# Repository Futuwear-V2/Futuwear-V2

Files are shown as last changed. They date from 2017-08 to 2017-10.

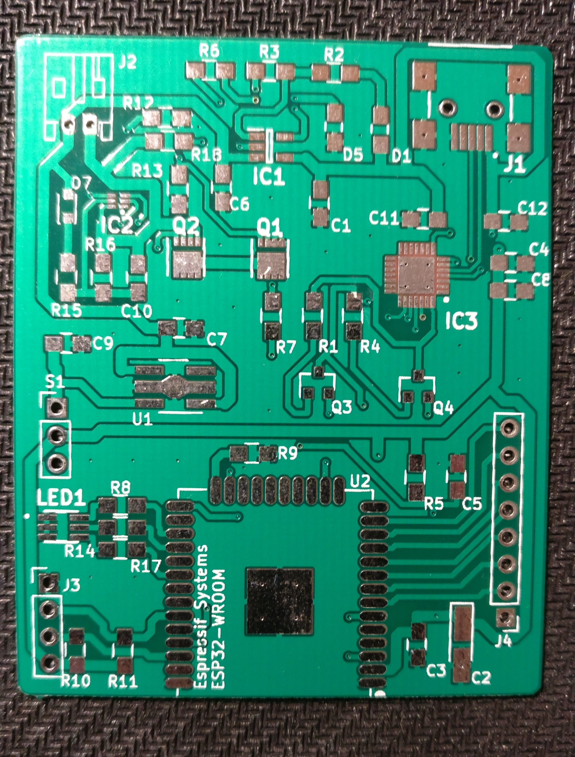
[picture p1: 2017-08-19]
Nettisivu/images/pcb_irl_no_components.jpg

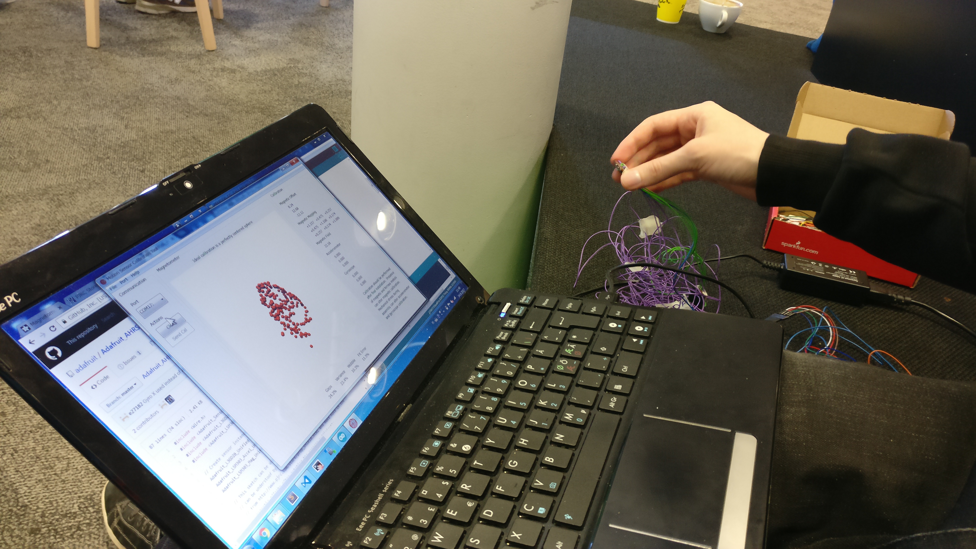
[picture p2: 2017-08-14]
Nettisivu/images/Magnetometer_test.jpg

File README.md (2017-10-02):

# Futuwear-V2
Protopaja 2017 group 11

Smart clothing motion capture shirt using ESP32 microcontroller and MPU-9250 IMUs.

To install the Arduino code on your ESP32, you need https://github.com/espressif/arduino-esp32 and the provided libraries. If you use the schematic, please note that the EN and IO0 pins need to be connected to ground when you upload the code to the device.

Guide on how to setup the server in /Server/README.md

Promotional website in /Nettisivu

Group members:
Jere Pylkkänen
Bruce Clayhills
Elliot Kölhi

https://protopaja.aalto.fi/futuricec/

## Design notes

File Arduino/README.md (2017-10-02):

# Futuwear-V2
How to setup the Arduino code on ESP32:
1. Install Arduino IDE and https://github.com/espressif/arduino-esp32
2. Copy the provided libraries to your Arduino libraries folder (usually Documents/Arduino/libraries on Windows)
3. Configure the WiFi settings and the IP address of the UDP server in FutuwearV2_UDP.ino
4. Upload FutuwearV2_UDP.ino to your ESP32

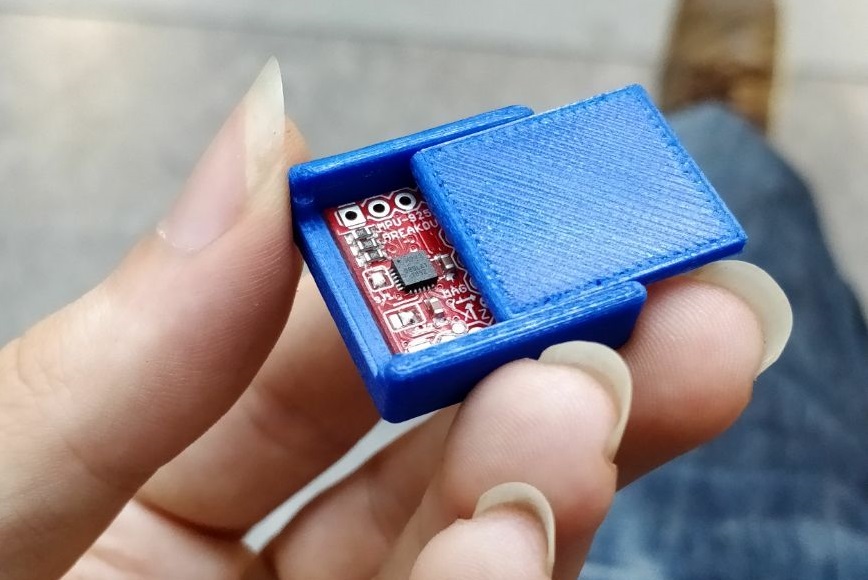
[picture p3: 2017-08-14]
Nettisivu/images/MPU-9250_IRL.jpg

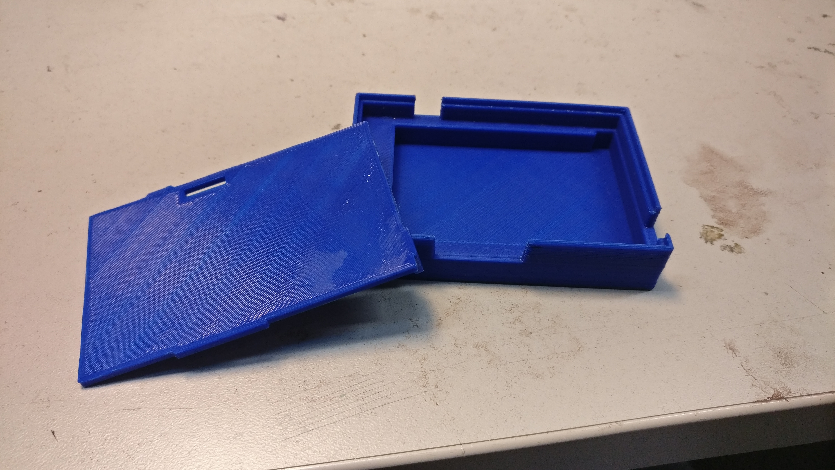
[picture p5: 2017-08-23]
Nettisivu/images/pcb_case_lid.jpg

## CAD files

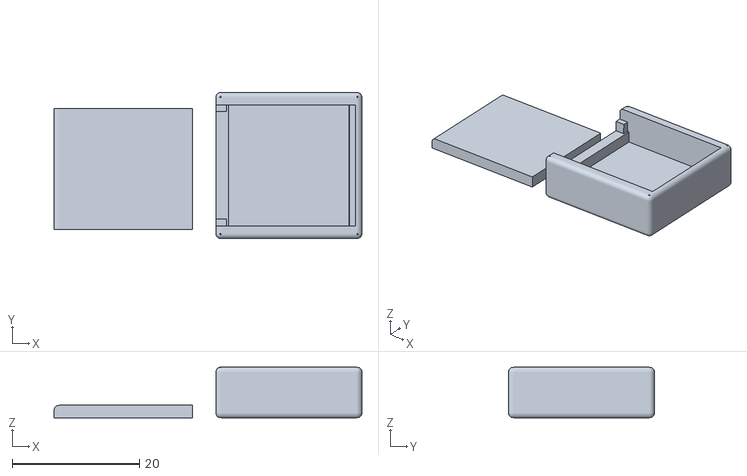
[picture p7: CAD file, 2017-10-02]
Enclosures/IMU/IMU case Final.stl
48.5 x 23.0 x 8.00

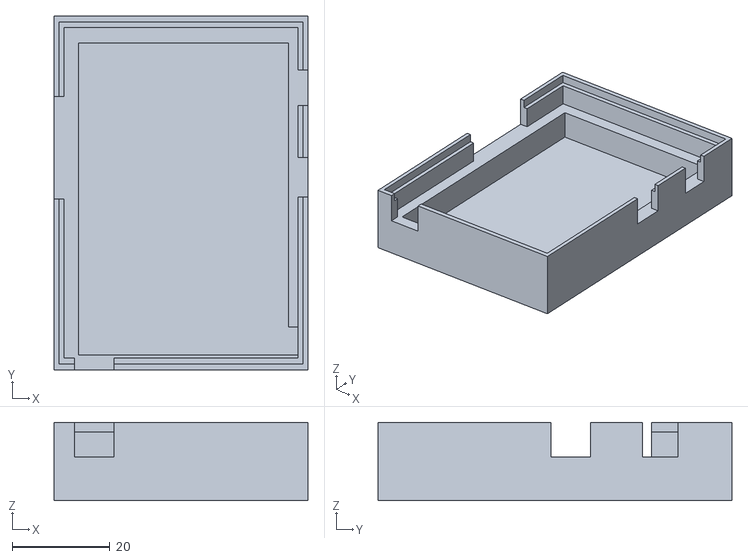
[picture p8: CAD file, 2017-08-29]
Enclosures/pcb enclosure bottom.stl
52.0 x 72.5 x 16.0

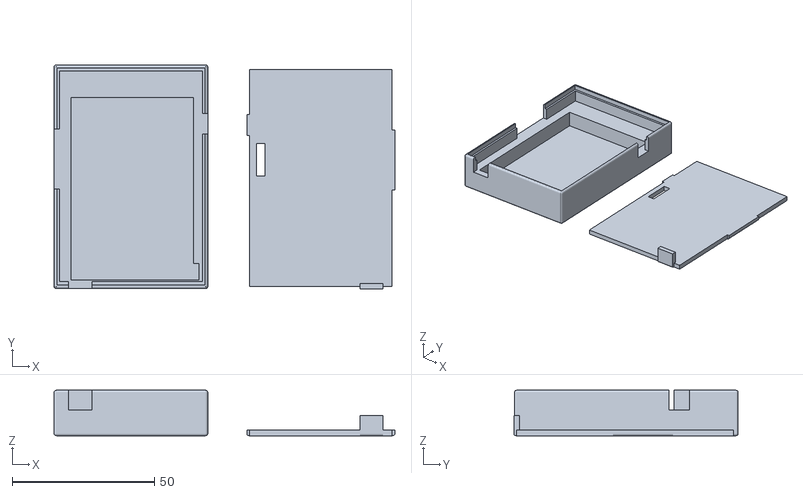
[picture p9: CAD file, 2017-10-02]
Enclosures/PCB/pcb enclosure final.stl
119.7 x 78.7 x 16.0

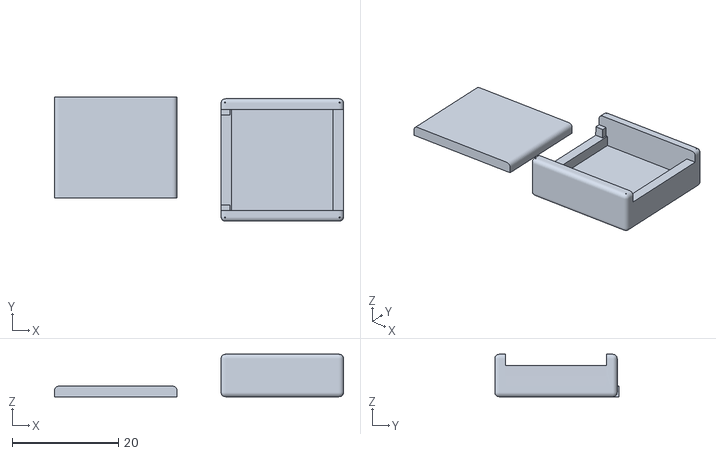
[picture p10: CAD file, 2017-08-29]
Enclosures/imu case 3.stl
54.3 x 23.4 x 8.00

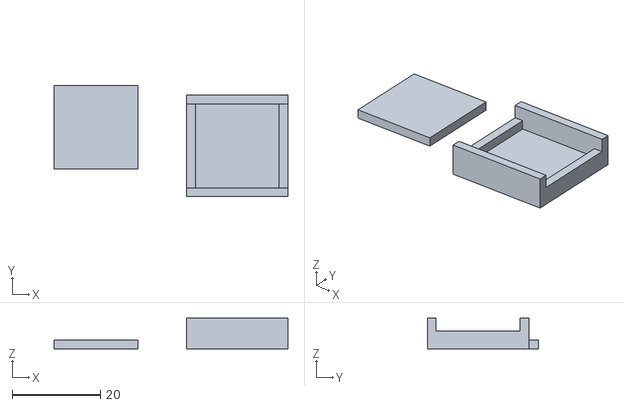
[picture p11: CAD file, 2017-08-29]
Enclosures/IMU enclosure final.stl
53.0 x 25.2 x 7.00

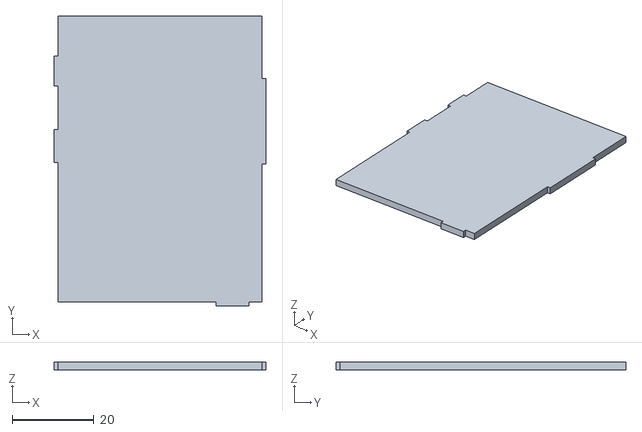
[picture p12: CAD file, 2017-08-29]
Enclosures/pcb enclosure top.stl
52.0 x 71.1 x 2.00

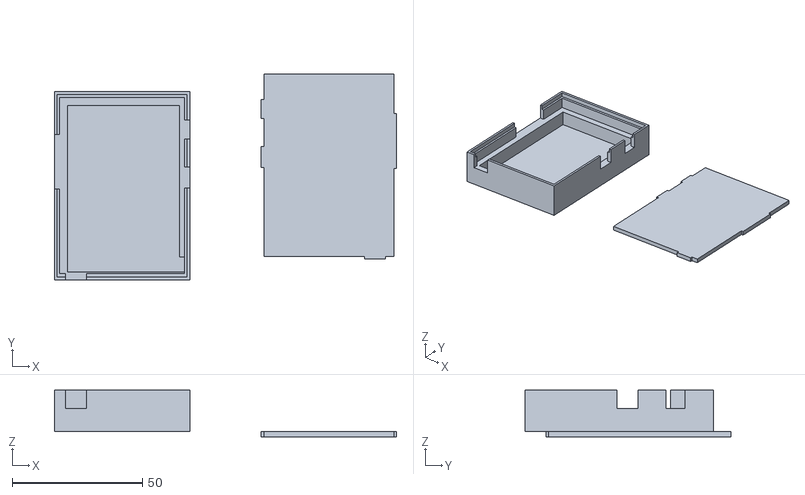
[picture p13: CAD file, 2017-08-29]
Enclosures/pcb enclosure 1.stl
131.4 x 79.2 x 18.0

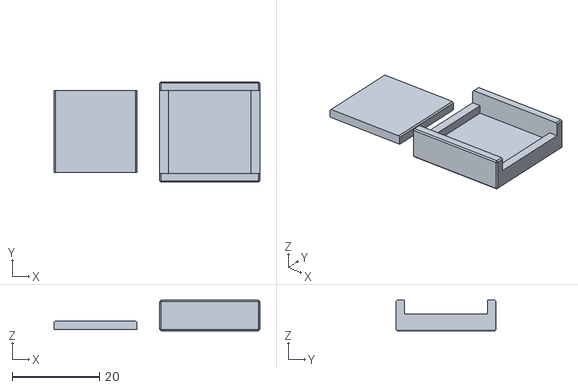
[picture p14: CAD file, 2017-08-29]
Enclosures/imu case 2.stl
47.2 x 23.0 x 7.00

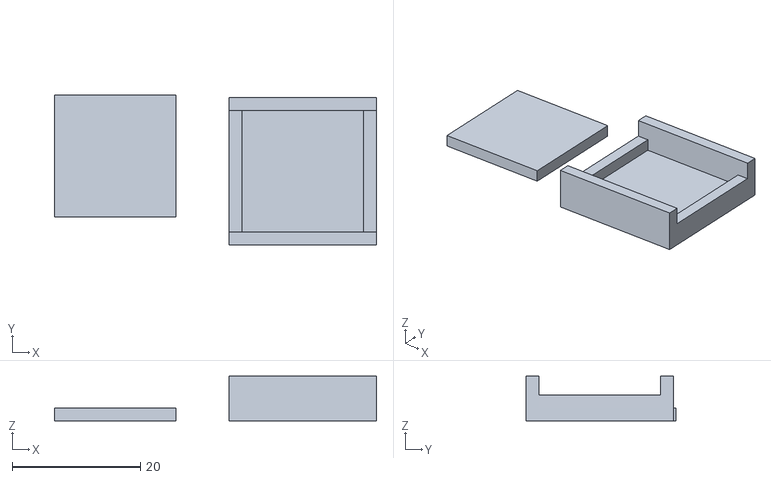
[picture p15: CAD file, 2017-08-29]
Enclosures/imu case.stl
50.3 x 23.4 x 7.00

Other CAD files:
Enclosures/IMU/Old versions/imu case 1.stl
Enclosures/PCB/Old versions/pcb enclosure 1.stl
Enclosures/IMU/Old versions/IMU enclosure 0.stl
Enclosures/PCB/Old versions/pcb enclosure top.stl
Enclosures/IMU/Old versions/imu case 2.stl
Enclosures/PCB/Old versions/pcb enclosure bottom.stl
Enclosures/IMU/Old versions/imu case 3.stl
Enclosures/IMU/IMU enclosure final.skp
Enclosures/PCB/Old versions/Untitled2.skp
Enclosures/PCB/Old versions/pcb enclosure 1.skp
Enclosures/PCB/pcb enclosure final.skp
Enclosures/Untitled2.skp
Enclosures/pcb enclosure 1.skp

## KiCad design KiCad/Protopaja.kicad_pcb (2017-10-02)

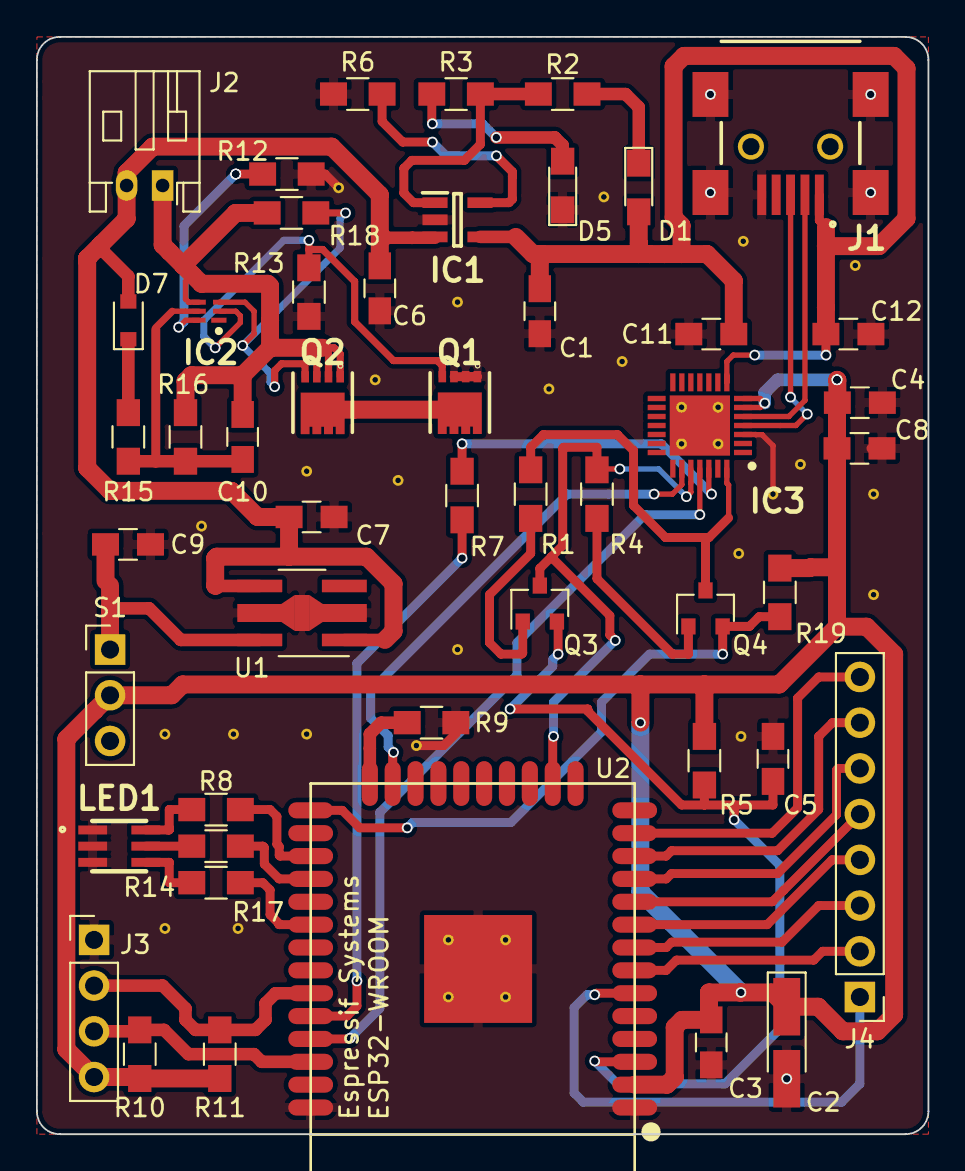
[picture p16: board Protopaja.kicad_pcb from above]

Board: 2 copper layers, 49.5 x 61.0 mm, 49 parts (0 on the bottom side), 45 nets.

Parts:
C1, C4, C6, C11: 10uF; C_0805_HandSoldering
C2: 100uF-TTL; CP_Tantalum_Case-A_EIA-3216-18_Hand
C3, C7: 1uF; C_0805_HandSoldering
C5: 1nF; C_0805_HandSoldering
C8, C10, C12: 0.1uF; C_0805_HandSoldering
C9: 2uF; C_0805_HandSoldering
D1, D5: LED; LED_0805_HandSoldering
D7: D; D_0805
IC1: MCP73831T-2ATI_OT; SOT95P270X145-5N
IC2: BQ29733DSER; DSE_(S-PWSON-N6)
IC3: CP2102-GM; QFN50P500X500X100-29N
J1: USB_OTG; 10033526-XXX1XX
J2: B2B-PH-K-S(LF)(SN); JST_PH_S2B-PH-K_02x2.00mm_Angled
J3: CONN_01X04; Pin_Header_Straight_1x04_Pitch2.54mm
J4: CONN_01X08; Pin_Header_Straight_1x08_Pitch2.54mm
LED1: ASMT-YTC7-0AA02
Q1, Q2: CSD17575Q3; CSD16327
Q3, Q4: PBSS4120T; SOT-23
R1, R4, R5: 12KΩ; R_0805_HandSoldering
R2, R3: 1KΩ; R_0805_HandSoldering
R6: 2KΩ; R_0805_HandSoldering
R7: 470Ω; R_0805_HandSoldering
R8, R14: 40Ω; R_0805_HandSoldering
R9: 5KΩ; R_0805_HandSoldering
R10, R11: 10KΩ; R_0805_HandSoldering
R12: 2.2KΩ; R_0805_HandSoldering
R13, R18: 5MΩ; R_0805_HandSoldering
R15: 330Ω; R_0805_HandSoldering
R16: 1MΩ; R_0805_HandSoldering
R17: 240Ω; R_0805_HandSoldering
R19: R_0805_HandSoldering
S1: 09.03201.02; Pin_Header_Straight_1x03_Pitch2.54mm
U1: XC6210B332PR; SOT89-5_Housing_Handsoldering
U2: ESP32-WROOM

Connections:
+3V3: C2.1, C3.1, C4.1, C8.1, IC3.6, IC3.7, J3.4, R5.1, R10.2, R11.1, R19.2, S1.2, U2.2
+BATT: C6.1, C7.1, D7.2, IC1.3, J2.2, U1.1, U1.4
/-BATT: C10.2, IC2.4, J2.1, Q2.1, Q2.2, Q2.3, R16.2, R18.2
/CTS: IC3.23, U2.23
/DTR: IC3.28, Q4.3, R1.1
/EN: C5.1, Q3.2, R5.2, U2.3
/GPIO14: J4.8, U2.13
/GPIO16: R8.1, U2.27
/GPIO17: R14.2, U2.28
/GPIO18: R17.2, U2.30
/GPIO25: J4.5, U2.10
/GPIO26: J4.6, U2.11
/GPIO27: J4.7, U2.12
/GPIO32: J4.3, U2.8
/GPIO33: J4.4, U2.9
/GPIO34: J4.1, U2.6
/GPIO35: J4.2, U2.7
/IO0: Q4.2, R19.1, U2.25
/IO13: IC3.24, Q3.3, R4.1, U2.16
/RXD: IC3.25, U2.35
/RXD0: R7.2, U2.34
/SCL: J3.3, R10.1, U2.36
/SDA: J3.2, R11.2, U2.33
D+: IC3.4, J1.3
D-: IC3.5, J1.2
GND: C1.2, C2.2, C3.2, C4.2, C5.2, C6.2, C7.2, C8.2, C9.2, C11.2, C12.2, D5.1, IC1.2, IC3.3, IC3.29, J1.5, J1.6, J1.7, J1.8, J1.9, J3.1, LED1.1, LED1.2, LED1.3, Q1.1, Q1.2, Q1.3, R6.2, R9.2, R12.1, R13.2, U1.2, U2.1, U2.38, U2.39
unnamed: C9.1, S1.1, U1.5
unnamed: C10.1, IC2.5, R15.1, R16.1
unnamed: D1.1, R2.1
unnamed: D5.2, R3.2
unnamed: D7.1, R15.2
unnamed: IC1.1, R2.2, R3.1
unnamed: IC1.5, R6.1
unnamed: IC2.2, Q1.4, R13.1
unnamed: IC2.3, Q2.4, R18.1
unnamed: IC2.6, R12.2
unnamed: IC3.26, R7.1
unnamed: LED1.4, R17.1
unnamed: LED1.5, R14.1
unnamed: LED1.6, R8.2
unnamed: Q1.5, Q1.6, Q1.7, Q1.8, Q1.9, Q2.5, Q2.6, Q2.7, Q2.8, Q2.9
unnamed: Q3.1, R1.2
unnamed: Q4.1, R4.2
unnamed: R9.1, U2.24
USB_IN: C1.1, C11.1, C12.1, D1.2, IC1.4, IC3.8, J1.1

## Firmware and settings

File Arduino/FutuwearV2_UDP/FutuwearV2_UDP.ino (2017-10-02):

/*
  Collects data from IMU sensors (MPU-9250), processes it, and sends it forward
  over WiFi as raw UDP packets.

  Based on https://github.com/sparkfun/SparkFun_MPU-9250_Breakout_Arduino_Library
*/

const char *SSID = "aalto open";
const char *PASSWORD = "";
const char *udpAddress = "195.148.124.218";
const int udpPort = 8082;

#include "quaternionFilters_FW2.h"
#include "MPU9250_FW2.h"

#include <WiFi.h>
#include <WiFiUdp.h>

#define PI_F 3.141593f

#define SERIAL_OUTPUT
#define DELAY 10

// RGB LED pins
#define LED_R 5
#define LED_G 15
#define LED_B 2

#define N_IMUS 1

// #define CALIBRATE_MAG
#define CALIBRATION_DELAY 1000
#define CALIBRATION_DURATION 1

MPU9250 IMU[N_IMUS] = {MPU9250(16)};
Quaternion Quat[N_IMUS];
WiFiUDP udp;

bool connected = false;

//char IMUbytes[4 * N_IMUS + 1];
uint8_t IMUbytes[20];
String encodedData;

//int16_t previousValues[N_IMUS][3]; 
int16_t previousValues[5][3];

void setup()
{
  pinMode(LED_R, OUTPUT);
  pinMode(LED_G, OUTPUT);
  pinMode(LED_B, OUTPUT);
  setRGB(0, 0, 1);
#ifdef SERIAL_OUTPUT
  Serial.begin(115200);
#endif
  Wire.begin();
  Wire.setClock(100000);

  setRGB(1, 0, 0);
  for (int i = 0; i < N_IMUS; i++)
    InitMPU(IMU[i]);

#ifdef CALIBRATE_MAG
  CalibrateMag();
#else
  IMU[0].magBias[0] = -100;
  IMU[0].magBias[1] = 165;
  IMU[0].magBias[2] = 70;
#endif

  setRGB(0, 1, 0);
  connectToWiFi();
}

unsigned long outputTimer = 0;

void loop()
{
  // Try to read all IMUs
  for (int i = 0; i < N_IMUS; i++)
    ReadMPU(i);
    
  // Output data every DELAY milliseconds
  if (connected && (outputTimer <= millis())) {
    outputTimer = millis() + DELAY;

    bool change = false;

    for (int i = 0; i < N_IMUS; i++) {
      float *q = (float*)Quat[i].getQ();

      // Calculate yaw, pitch and roll from the quaternion
      // Angles are sent as integers with value from 0 to 1624 packed into
      // one unsigned long (32 bits)
      int16_t yaw   = (atan2f(2.0f * (q[1] * q[2] + q[0] * q[3]), q[0] * q[0] +
                       q[1] * q[1] - q[2] * q[2] - q[3] * q[3]) + PI_F) * 258.467621f;
      int16_t pitch = (-asinf(2.0f * (q[1] * q[3] - q[0] * q[2])) + PI_F) * 258.467621f;
      int16_t roll  = (atan2f(2.0f * (q[0] * q[1] + q[2] * q[3]), q[0] * q[0] -
                       q[1] * q[1] - q[2] * q[2] + q[3] * q[3]) + PI_F) * 258.467621f;

      // Compare values to previously sent values
      if (!change && (abs(yaw   - previousValues[i][0]) > 5 ||
                      abs(pitch - previousValues[i][1]) > 5 ||
                      abs(roll  - previousValues[i][2]) > 5))
        change = true;

      previousValues[i][0] = yaw;
      previousValues[i][1] = pitch;
      previousValues[i][2] = roll;

      uint32_t IMUdata = pitch * 1625 * 1625 + yaw * 1625 + roll;

      // IMUbytes[0 + i * 4] = (IMUdata >> 24) & 0xFF;
      // IMUbytes[1 + i * 4] = (IMUdata >> 16) & 0xFF;
      // IMUbytes[2 + i * 4] = (IMUdata >>  8) & 0xFF;
      // IMUbytes[3 + i * 4] =  IMUdata        & 0xFF;
      for (int k = 0; k < 5; k++) {
        IMUbytes[0 + k * 4] = (IMUdata >> 24) & 0xFF;
        IMUbytes[1 + k * 4] = (IMUdata >> 16) & 0xFF;
        IMUbytes[2 + k * 4] = (IMUdata >>  8) & 0xFF;
        IMUbytes[3 + k * 4] =  IMUdata        & 0xFF;
      }
    }

    if (change) {
      udp.beginPacket(udpAddress,udpPort);
      udp.write(IMUbytes, 20);
      udp.endPacket();
    }
  }
}

void setRGB(int R, int G, int B)
{
  digitalWrite(LED_R, R);
  digitalWrite(LED_G, G);
  digitalWrite(LED_B, B);
}

void ReadMPU(int i)
{
  if (IMU[i].readByte(MPU9250_ADDRESS, INT_STATUS) & 0x01)
  {
    IMU[i].writeByte(MPU9250_ADDRESS, INT_PIN_CFG, 0x22);
    delayMicroseconds(100);

    IMU[i].readAccelData(IMU[i].accelCount);  // Read the x/y/z adc values
    IMU[i].ax = (float)IMU[i].accelCount[0] * IMU[i].aRes - IMU[i].accelBias[0];
    IMU[i].ay = (float)IMU[i].accelCount[1] * IMU[i].aRes - IMU[i].accelBias[1];
    IMU[i].az = (float)IMU[i].accelCount[2] * IMU[i].aRes - IMU[i].accelBias[2];

    IMU[i].readGyroData(IMU[i].gyroCount);  // Read the x/y/z adc valu
    IMU[i].gx = ((float)IMU[i].gyroCount[0] * IMU[i].gRes - IMU[i].gyroBias[0]) * 0.0174533f;
    IMU[i].gy = ((float)IMU[i].gyroCount[1] * IMU[i].gRes - IMU[i].gyroBias[1]) * 0.0174533f;
    IMU[i].gz = ((float)IMU[i].gyroCount[2] * IMU[i].gRes - IMU[i].gyroBias[2]) * 0.0174533f;

    IMU[i].readMagData(IMU[i].magCount);  // Read the x/y/z adc values
    IMU[i].mx = - (float)IMU[i].magCount[1] * IMU[i].mRes * IMU[i].factoryMagCalibration[1] - IMU[i].magBias[1];
    IMU[i].my = - (float)IMU[i].magCount[0] * IMU[i].mRes * IMU[i].factoryMagCalibration[0] - IMU[i].magBias[0];
    IMU[i].mz =   (float)IMU[i].magCount[2] * IMU[i].mRes * IMU[i].factoryMagCalibration[2] - IMU[i].magBias[2];
    IMU[i].writeByte(MPU9250_ADDRESS, INT_PIN_CFG, 0x20);

    Quat[i].MahonyQuaternionUpdate(IMU[i].ax, IMU[i].ay, IMU[i].az,
                                   IMU[i].gx, IMU[i].gy, IMU[i].gz,
                                   IMU[i].mx, IMU[i].my, IMU[i].mz);
  } // if (readByte(MPU9250_ADDRESS, INT_STATUS) & 0x01)
}


void connectToWiFi(){
  // delete old config
  WiFi.disconnect(true);
  //register event handler
  WiFi.onEvent(WiFiEvent);
  //Initiate connection
  WiFi.begin(SSID, PASSWORD);

#ifdef SERIAL_OUTPUT
  Serial.println("Waiting for WIFI connection...");
#endif
}

//wifi event handler
void WiFiEvent(WiFiEvent_t event){
  switch(event) {
    case SYSTEM_EVENT_STA_GOT_IP:
      //When connected set
#ifdef SERIAL_OUTPUT
      Serial.print("WiFi connected! IP address: ");
      Serial.println(WiFi.localIP());
#endif
      //initializes the UDP state
      //This initializes the transfer buffer
      udp.begin(WiFi.localIP(), udpPort);
      connected = true;
      break;
    case SYSTEM_EVENT_STA_DISCONNECTED:
#ifdef SERIAL_OUTPUT
      Serial.println("WiFi lost connection");
#endif
      connected = false;
    default:
      break;
  }
}

void InitMPU(MPU9250 &mpu)
{
  // Read the WHO_AM_I register, this is a good test of communication
  byte c = mpu.readByte(MPU9250_ADDRESS, WHO_AM_I_MPU9250);
#ifdef SERIAL_OUTPUT
  Serial.print(F("MPU9250 I AM 0x"));
  Serial.print(c, HEX);
  Serial.print(F(" I should be 0x"));
  Serial.println(0x71, HEX);
#endif

  if (c != 0x71) { // WHO_AM_I should always be 0x71
#ifdef SERIAL_OUTPUT
    Serial.print("Could not connect to MPU9250: 0x");
    Serial.println(c, HEX);

    // Communication failed, stop here
    Serial.println(F("Communication failed, abort!"));
    Serial.flush();
#endif
    setRGB(1, 0, 0);
    abort();
  }

#ifdef SERIAL_OUTPUT
  Serial.println(F("MPU9250 is online..."));
#endif

  // Start by performing self test and reporting values
  mpu.MPU9250SelfTest(mpu.selfTest);
#ifdef SERIAL_OUTPUT
  Serial.print(F("x-axis self test: acceleration trim within : "));
  Serial.print(mpu.selfTest[0],1); Serial.println("% of factory value");
  Serial.print(F("y-axis self test: acceleration trim within : "));
  Serial.print(mpu.selfTest[1],1); Serial.println("% of factory value");
  Serial.print(F("z-axis self test: acceleration trim within : "));
  Serial.print(mpu.selfTest[2],1); Serial.println("% of factory value");
  Serial.print(F("x-axis self test: gyration trim within : "));
  Serial.print(mpu.selfTest[3],1); Serial.println("% of factory value");
  Serial.print(F("y-axis self test: gyration trim within : "));
  Serial.print(mpu.selfTest[4],1); Serial.println("% of factory value");
  Serial.print(F("z-axis self test: gyration trim within : "));
  Serial.print(mpu.selfTest[5],1); Serial.println("% of factory value");
#endif

  // Calibrate gyro and accelerometers, load biases in bias registers
  mpu.calibrateMPU9250(mpu.gyroBias, mpu.accelBias);

  mpu.initMPU9250();
  // Initialize device for active mode read of acclerometer, gyroscope, and
  // temperature
#ifdef SERIAL_OUTPUT
  Serial.println("MPU9250 initialized for active data mode....");
#endif

  // Read the WHO_AM_I register of the magnetometer, this is a good test of
  // communication
  byte d = mpu.readByte(AK8963_ADDRESS, WHO_AM_I_AK8963);
#ifdef SERIAL_OUTPUT
  Serial.print("AK8963 ");
  Serial.print("I AM 0x");
  Serial.print(d, HEX);
  Serial.print(" I should be 0x");
  Serial.println(0x48, HEX);
#endif

  if (d != 0x48) {
#ifdef SERIAL_OUTPUT
    Serial.print("Could not connect to AK8963: 0x");
    Serial.println(d, HEX);

    // Communication failed, stop here
    Serial.println(F("Communication failed, abort!"));
    Serial.flush();
#endif
    setRGB(1, 0, 0);
    abort();
  }

  // Get magnetometer calibration from AK8963 ROM
  mpu.initAK8963(mpu.factoryMagCalibration);
  // Initialize device for active mode read of magnetometer
#ifdef SERIAL_OUTPUT
  Serial.println("AK8963 initialized for active data mode....");

  //  Serial.println("Calibration values: ");
  Serial.print("X-Axis factory sensitivity adjustment value ");
  Serial.println(mpu.factoryMagCalibration[0], 2);
  Serial.print("Y-Axis factory sensitivity adjustment value ");
  Serial.println(mpu.factoryMagCalibration[1], 2);
  Serial.print("Z-Axis factory sensitivity adjustment value ");
  Serial.println(mpu.factoryMagCalibration[2], 2);
#endif

  // Get sensor resolutions, only need to do this once
  mpu.getAres();
  mpu.getGres();
  mpu.getMres();
    
  // Disable I2C bypass mode for AK8963
  mpu.writeByte(MPU9250_ADDRESS, INT_PIN_CFG, 0x20);
}

void CalibrateMag()
{
  uint16_t ii = 0, sample_count = 0;
  int32_t mag_bias[N_IMUS][3],
          mag_scale[N_IMUS][3];
  int16_t mag_max[N_IMUS][3],
          mag_min[N_IMUS][3],
          mag_temp[N_IMUS][3];

  for (int i = 0; i < N_IMUS; i++) {
    // Init values
    for (int k = 0; k < 3; k++) {
      mag_bias[i][k]  = 0;
      mag_scale[i][k] = 0;
      mag_max[i][k]   = 0;
      mag_min[i][k]   = 0x7FFF;
      mag_temp[i][k]  = 0;
    }
    // Make sure resolution has been calculated
    IMU[i].getMres();
  }

#ifdef SERIAL_OUTPUT
  Serial.println(F("Mag Calibration: Wave device in a figure 8 until done!"));
  Serial.println(F("  4 seconds to get ready followed by 15 seconds of sampling)"));
#endif
  delay(CALIBRATION_DELAY);

  // shoot for ~fifteen seconds of mag data
  // at 8 Hz ODR, new mag data is available every 125 ms
  sample_count = CALIBRATION_DURATION * 8;

  for (ii = 0; ii < sample_count; ii++)
  {
    for (int i = 0; i < N_IMUS; i++) {
      IMU[i].writeByte(MPU9250_ADDRESS, INT_PIN_CFG, 0x22);
      delayMicroseconds(100);
      IMU[i].readMagData(mag_temp[i]);  // Read the mag data
      IMU[i].writeByte(MPU9250_ADDRESS, INT_PIN_CFG, 0x20);

      for (int jj = 0; jj < 3; jj++)
      {
        if (mag_temp[i][jj] > mag_max[i][jj])
          mag_max[i][jj] = mag_temp[i][jj];
        if (mag_temp[i][jj] < mag_min[i][jj])
          mag_min[i][jj] = mag_temp[i][jj];
      }
    }

    delay(135); // At 8 Hz ODR, new mag data is available every 125 ms
  }

  for (int i = 0; i < N_IMUS; i++) {
    // Get hard iron correction
    // Get 'average' x mag bias in counts
    mag_bias[i][0]  = (mag_max[i][0] + mag_min[i][0]) / 2;
    // Get 'average' y mag bias in counts
    mag_bias[i][1]  = (mag_max[i][1] + mag_min[i][1]) / 2;
    // Get 'average' z mag bias in counts
    mag_bias[i][2]  = (mag_max[i][2] + mag_min[i][2]) / 2;

    // Save mag biases in G for main program
    IMU[i].magBias[0] = (float)mag_bias[i][0] * IMU[i].mRes * IMU[i].factoryMagCalibration[0];
    IMU[i].magBias[1] = (float)mag_bias[i][1] * IMU[i].mRes * IMU[i].factoryMagCalibration[1];
    IMU[i].magBias[2] = (float)mag_bias[i][2] * IMU[i].mRes * IMU[i].factoryMagCalibration[2];

    // Get soft iron correction estimate
    // Get average x axis max chord length in counts
    mag_scale[i][0]  = (mag_max[i][0] - mag_min[i][0]) / 2;
    // Get average y axis max chord length in counts
    mag_scale[i][1]  = (mag_max[i][1] - mag_min[i][1]) / 2;
    // Get average z axis max chord length in counts
    mag_scale[i][2]  = (mag_max[i][2] - mag_min[i][2]) / 2;

    float avg_rad = mag_scale[i][0] + mag_scale[i][1] + mag_scale[i][2];
    avg_rad /= 3.0;

    IMU[i].magScale[0] = avg_rad / ((float)mag_scale[i][0]);
    IMU[i].magScale[1] = avg_rad / ((float)mag_scale[i][1]);
    IMU[i].magScale[2] = avg_rad / ((float)mag_scale[i][2]);
  }

#ifdef SERIAL_OUTPUT
  Serial.println(F("Mag Calibration done!"));
#endif
}

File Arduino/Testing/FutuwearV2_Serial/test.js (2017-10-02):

// Sends serial port data to the server through a WebSocket

const WebSocket = require("ws");
const SerialPort = require("serialport");
const Readline = SerialPort.parsers.Readline;

const wsc = new WebSocket("wss://protopaja2.research.comnet.aalto.fi/ws")

var port = new SerialPort("COM1", {
  baudRate: 115200
});
const parser = port.pipe(new Readline({ delimiter: '\r\n' }));

wsc.on("open", () => {
    wsc.send("shirt");
    parser.on("data", (data) => {
        var str = Buffer.from(data, "base64");
        str = String(str);
            wsc.send(data);
        console.log(String(data));
    });
});

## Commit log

2017-08-14 Cleaned up the folder and moved stuff around. Fixed the probelms with the code and made the clickable button open a new tab.
2017-08-17 Changed the background to a picture and added the mysterious button link.
2017-08-23 Added Arduino and server code
2017-08-23 Added KiCad files.
    [Protopaja-B.Cu.gbl, Protopaja-B.Mask.gbs, Protopaja-B.SilkS.gbo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]
2017-08-29 3D Enclosures added
    [IMU case 4.stl, IMU enclosure final.skp, IMU enclosure final.stl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]
2017-08-29 Rename IMU enclosure final.stl to IMU enclosure early.stl
    [IMU enclosure early.stl]
2017-08-29 Sorted and renamed files
    [IMU case Final.stl, IMU enclosure 0.stl, IMU enclosure final.skp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]
2017-09-19 Added the final report and updated KiCad files
    [Protopaja.kicad_pcb, Protopaja.sch]
2017-10-02 Added Arduino readme
    [IMU case Final.stl, IMU enclosure 0.stl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]
